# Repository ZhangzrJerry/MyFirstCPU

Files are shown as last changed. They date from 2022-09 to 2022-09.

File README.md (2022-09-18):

# MyFirstCPU

## 设计说明

使用FPGA芯片XC3S250E，实现烧录和复位功能，支持2个7位数码管的输出和4个按键的输入读取



## 使用说明

1. **关于供电**
   1. 插入PCB左上角的type-c接口
   1. 按下PCB左上角POWER模块的按钮

1. **关于烧写程序**
   1. 按下PCB板右上角的load按钮
   1. 插入PCB右下角的micro-b接口

## 参考资料

- CPU自制入门/（日）水头一寿，（日）米泽辽，（日）藤田裕士著；赵谦译.--北京∶人民邮电出版社，2014.1（图灵程序设计丛书）ISBN 978-7-115-33818-1

- 《<CPU自制入门>笔记——第二章 电路板的设计与制作》 原文链接：https://blog.csdn.net/zysns/article/details/96426607

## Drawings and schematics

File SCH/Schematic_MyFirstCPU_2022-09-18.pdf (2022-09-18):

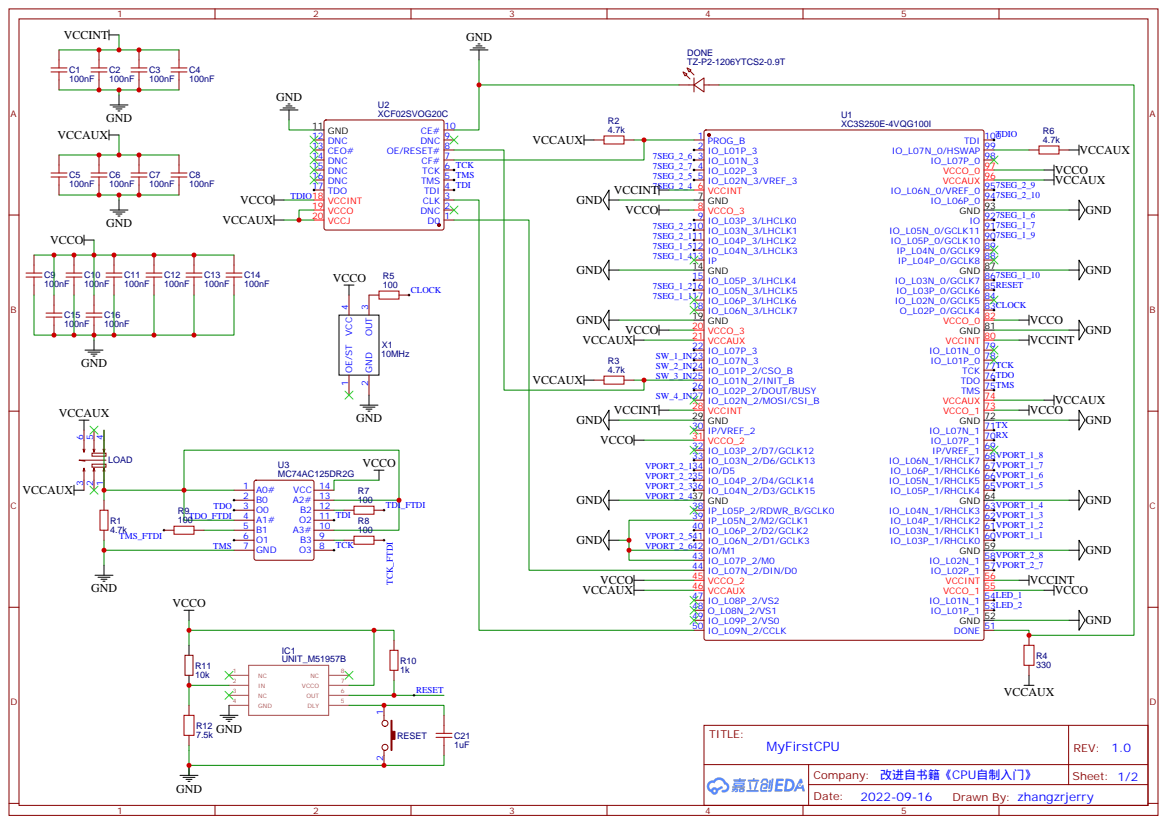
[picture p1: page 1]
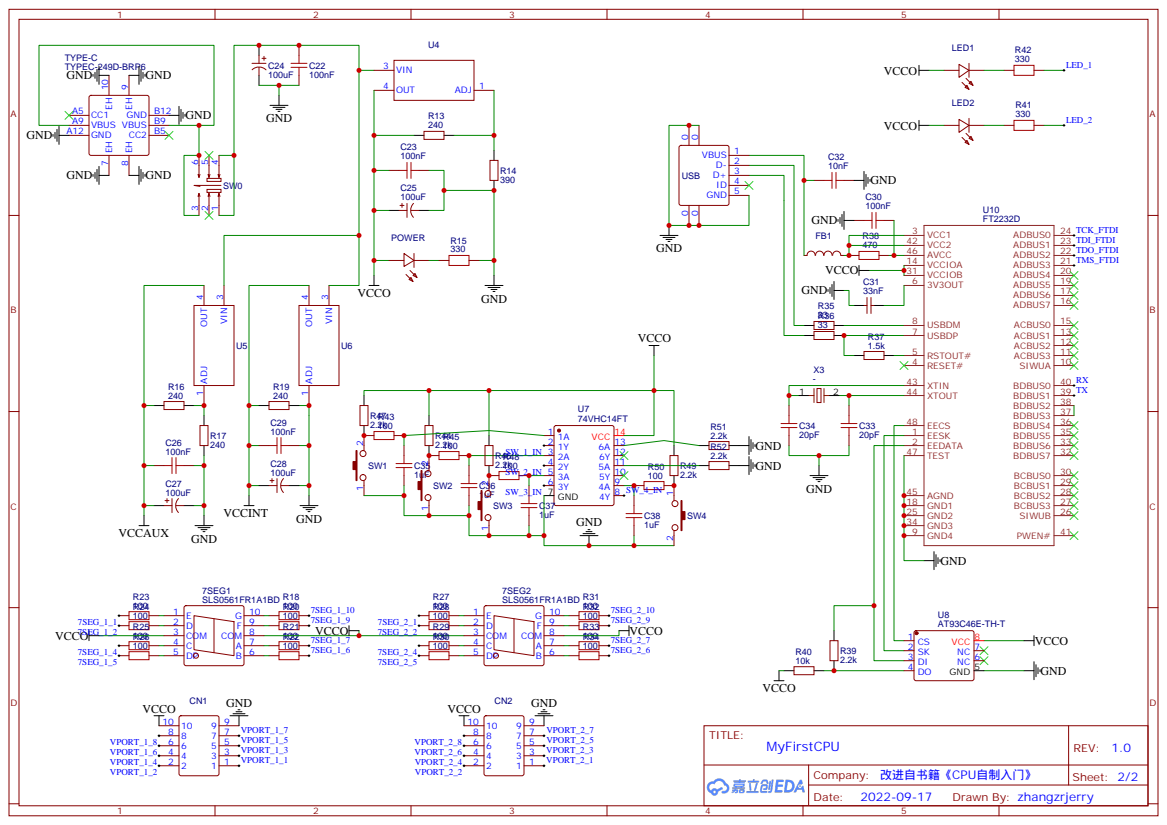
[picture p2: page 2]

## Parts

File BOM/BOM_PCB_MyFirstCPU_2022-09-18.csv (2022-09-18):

ID | Name | Designator | Footprint | Quantity | Manufacturer Part | Manufacturer | Supplier | Supplier Part | Price
1 | XKB5858-Z-TP | LOAD,SW0 | SW-SMD_6P-L5.8-W5.8-P2.00-LS8.3 | 2 | XKB5858-Z-TP | XKB Enterprise | LCSC | C381090 | 2.8
2 | SLS0561FR1A1BD | 7SEG2,7SEG1 | LED-SEG-SMD_SLS0561FR1A1BD | 2 | SLS0561FR1A1BD | SUNLIGHT | LCSC | C226002 | 3.41
3 | 100Ω | R27,R28,R29,R30,R31,R32,R33,R34,R5,R7,R8,R9,R18,R20,R21,R22,R23,R24,R25,R26,R43,R45,R48,R50 | R1206 | 24 | RMC12061001%N | Tyohm | LCSC | C325893 | 0.051
4 | 100nF | C1,C2,C3,C4,C5,C6,C7,C8,C9,C10,C11,C12,C13,C14,C15,C16,C22,C23,C26,C29,C30 | C1206 | 21 | GRM31MR71H104KA01L | muRata(村田) | LCSC | C469550 | 0.6532
5 | XC3S250E-4VQG100I | U1 | QFP-100_L14.0-W14.0-P0.50-LS16.0-BL | 1 | XC3S250E-4VQG100I | XILINX(赛灵思) | LCSC | C2684980 | 140.26
6 | XCF02SVOG20C | U2 | TSSOP-20_L6.5-W4.4-P0.65-LS6.4-BL | 1 | XCF02SVOG20C | XILINX(赛灵思) | LCSC | C569040 | 621.5
7 | MC74AC125DR2G | U3 | SOIC-14_L8.7-W3.9-P1.27-LS6.0-BL | 1 | MC74AC125DR2G | ON | LCSC | C99675 | 2.0715
8 | 10MHz | X1 | OSC-SMD_4P-L7.0-W5.0-BL_SG7050 | 1 | X1G004481000500 | EPSON | LCSC | C16850 | 2.44
9 | 1uF | C21 | C1206 | 1 | CL31A105KB9LNNC | Samsung Electro-Mechanics | LCSC | C444884 | 0.0964
10 | 100uF | C24,C25,C27,C28 | CAP-SMD_BD6.3-L6.6-W6.6-LS7.2-FD | 4 | RVT100UF16V67RV0016 | KNSCHA(科尼盛) | LCSC | C2887276 | 0.1812
11 | 33nF | C31 | C1206 | 1 | GRM3195C1H333JA01D | MuRata | LCSC | C97930 | 0.6792
12 | 10nF | C32 | C1206 | 1 | TCC1206X7R103K501DTS | CCTC | LCSC | C377058 | 0.0639
13 | 20pF | C33,C34 | C1206 | 2 | CC1206JRNPO9BN200 | YAGEO | LCSC | C113883 | 0.1675
14 | 1uF | C35,C36,C37,C38 | C1206 | 4 | CL31B105KBHNNNE | SAMSUNG | LCSC | C1848 | 0.0846
15 | Z-231011810106 | CN1,CN2 | IDC-TH_Z-231011810106 | 2 | Z-231011810106 | ZHENGLING | LCSC | C93713 | 1.363
16 | TZ-P2-1206YTCS2-0.9T | DONE | LED1206-RD_YELLOW-1 | 1 | TZ-P2-1206YTCS2-0.9T | TUOZHAN | LCSC | C779811 | 0.0669
17 | PZ3216U601-1R5TF | FB1 | L1206 | 1 | PZ3216U601-1R5TF | Sunlord | LCSC | C370100 | 0.2057
18 | UNIT_M51957B | IC1 | SMD_SOP8 | 1
19 | E6C1206CWAY1UDA | LED1,LED2 | LED1206-RD_WHITE | 2 | E6C1206CWAY1UDA | EKINGLUX | LCSC | C375462 | 0.2207
20 | E6C1206QBAC1UDA | POWER | LED1206-R-RD | 1 | E6C1206QBAC1UDA | EKINGLUX | LCSC | C375460 | 0.1626
21 | 4.7kΩ | R1,R2,R3,R6 | R1206 | 4 | CR-06JL7---4K7 | Viking Tech | LCSC | C280050 | 0.0192
22 | 330Ω | R4,R15,R41,R42 | R1206 | 4 | MCR18EZPJ331 | ROHM Semicon | LCSC | C507456 | 0.057
23 | 1kΩ | R10 | R1206 | 1 | RMC12061K5%N | Tyohm | LCSC | C269755 | 0.0435
24 | 10kΩ | R11,R40 | R1206 | 2 | 1206W4J0103T5E | UniOhm | LCSC | C1489 | 0.0178
25 | 7.5kΩ | R12 | R1206 | 1 | AS0606J0752T5E | UNI-ROYAL(Uniroyal Elec) | LCSC | C966034 | 0.0912
26 | 240Ω | R13,R16,R17,R19 | R1206 | 4 | 1206W4F2400T5E | UniOhm | LCSC | C17961 | 0.0191
27 | 390Ω | R14 | R1206 | 1 | 1206W4J0391T5E | UniOhm | LCSC | C25378 | 0.0127
28 | 33Ω | R35,R36 | R1206 | 2 | 1206W4J0330T5E | UniOhm | LCSC | C25375 | 0.0188
29 | 1.5kΩ | R37 | R1206 | 1 | 1206W4F1501T5E | UniOhm | LCSC | C26030 | 0.0196
30 | 470Ω | R38 | R1206 | 1 | RS-06K471JT | FH | LCSC | C118071 | 0.0156
31 | 2.2kΩ | R39,R44,R46,R47,R49,R51,R52 | R1206 | 7 | 1206W4J0222T5E | UniOhm | LCSC | C26038 | 0.0124
32 | TC | RESET,SW1,SW2,SW3,SW4 | KEY-SMD_L6.0-W3.6-LS8.3-L | 5 | TC-3602-4.3-260GKK | HCTL(华灿天禄) | LCSC | C3012022 | 0.2512
33 | TYPEC-249D-BRP6 | TYPE-C | USB-C-SMD_XUNPU_TYPEC-249D-BRP6 | 1 | TYPEC-249D-BRP6 | XUNPU(讯普) | LCSC | C2895023 | 0.5481
34 | LM317AG-TN3-R | U4,U5,U6 | TO-252-2_L6.5-W6.1-P4.58-LS10.0-TL | 3 | LM317AG-TN3-R | UTC | LCSC | C75510 | 1.1963
35 | 74VHC14FT | U7 | TSSOP-14_L5.0-W4.4-P0.65-LS6.4-BL | 1 | 74VHC14FT | TOSHIBA | LCSC | C80863 | 0.8694
36 | AT93C46E-TH-T | U8 | TSSOP-8_L4.4-W3.0-P0.65-LS6.4-BL-2 | 1 | AT93C46E-TH-T | Microchip Tech | LCSC | C184789 | 1.4667
37 | FT2232D | U10 | LQFP-48_L7.0-W7.0-P0.50-LS9.0-BL | 1 | FT2232D | FTDI | LCSC | C8938 | 158.69
38 | U254-051N-4BH83-F1B | USB | MICRO-USB-SMD_U254-051N-4BH83-F1B | 1 | U254-051N-4BH83-F1B | XKB Enterprise | LCSC | C319169 | 0.361
39 | - | X3 | CRYSTAL-SMD_L11.4-W4.8-LS12.7 | 1 | TAXM6M2IHDBET2T | TAE(雅晶鑫) | LCSC | C696838 | 0.6634
